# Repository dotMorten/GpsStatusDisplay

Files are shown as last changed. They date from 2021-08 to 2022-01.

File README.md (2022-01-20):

# High Accuracy GPS Device Build


Build your own survey-grade super-accurate GPS Device at a fraction of the cost.
The below list will run you around $300 (mainly for the advanced GPS chip), but will rival high-end GPS receivers that'll often cost you up towards $10000, not to mention you get a built-in interface for configuring the device, instead of relying on external desktop or mobile software.

### Features:
 - Up to 10mm accuracy with RTCM Correction Source
 - 128x128 RGB OLED Display for status and configuration
 - Bluetooth and Serial Port connections
 - 5-way button to control display and configure device
 
 ### Parts List:
 1. High-accuracy GPS Chip: [SparkFun GPS-RTK2 Board - ZED-F9P (Qwiic) High-Precision Breakout](https://amzn.to/2HEfFoN)
 2. GNSS Multi-Band Antenna : [GNSS Multi-Band Magnetic Mount Antenna - 5m (SMA)](https://www.sparkfun.com/products/15192)
 3. Antenna Ground Plate: [GPS Antenna Ground Plate](https://www.sparkfun.com/products/15004)
 4. UFL-to-SMA antenna connector: [Karcy Mini PCI UFL to SMA Female Connector](https://amzn.to/34DS7c4)
 5. Bluetooth chip: [SparkFun Bluetooth Silvermate](https://amzn.to/35LofKn)
 6. Arduino: [SparkFun Thing Plus - SAMD51](https://amzn.to/3kK7pSq)
 7. Display: [Waveshare 1.5inch RGB OLED Display Module](https://amzn.to/3oGIIsc)
 8. Buttons: 4 6x6mm tactile buttons
 9. Qwiic connector: [SparkFun Qwiic Cable Kit Hook Up](https://amzn.to/2TBvj6r)
 10. Various cables/connectors for soldering it all together
 
You really only need 1-4, if you don't need a display. Add 5 if you want bluetooth. However without the Arduino, display and buttons, all configuration has to be done via the u-blox desktop software.
For antenna you can pretty much use any GPS antenna rated for multi-band L1 and L2, but the above combined with the ground plate is likely the cheapest option while supporting full 10mm RTK.

### Resources

- [SparkFun GPS-RTK2 Hookup Guide](https://learn.sparkfun.com/tutorials/gps-rtk2-hookup-guide)
- [NmeaParser](https://github.com/dotMorten/NmeaParser) - My library to process NMEA data from the device, as well as sending it NTRIP Correction Data for full RTK 10mm accuracy
- [SparkFun u-blox Arduino Library](https://github.com/sparkfun/SparkFun_Ublox_Arduino_Library)
- [UcgLib](https://github.com/olikraus/ucglib) - Display library used for rendering to the OLED display

### Display example:
gpsdisplay_4
 
### Connection Diagram



### Accuracy

With an RTCM Correction source such as an NTRIP service, you can get down to around 10mm accuracy. As an example here's the point plot of 1000 measurements in RTK mode with an RTCM base station ~7.7 km away.



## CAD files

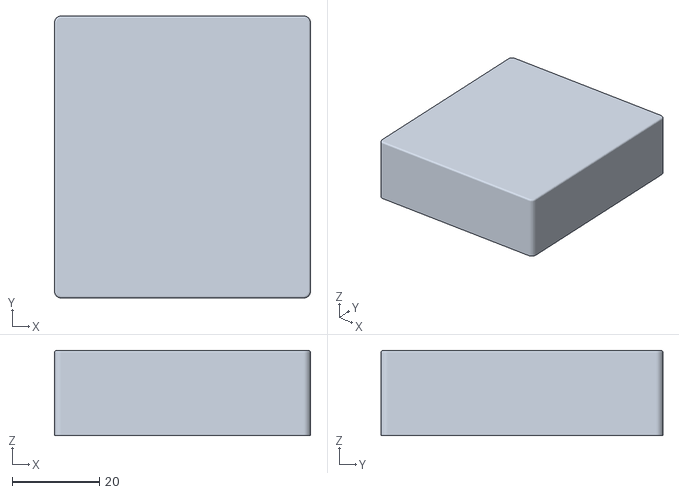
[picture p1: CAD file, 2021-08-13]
3dPrints/Box.stl
58.6 x 64.6 x 19.5

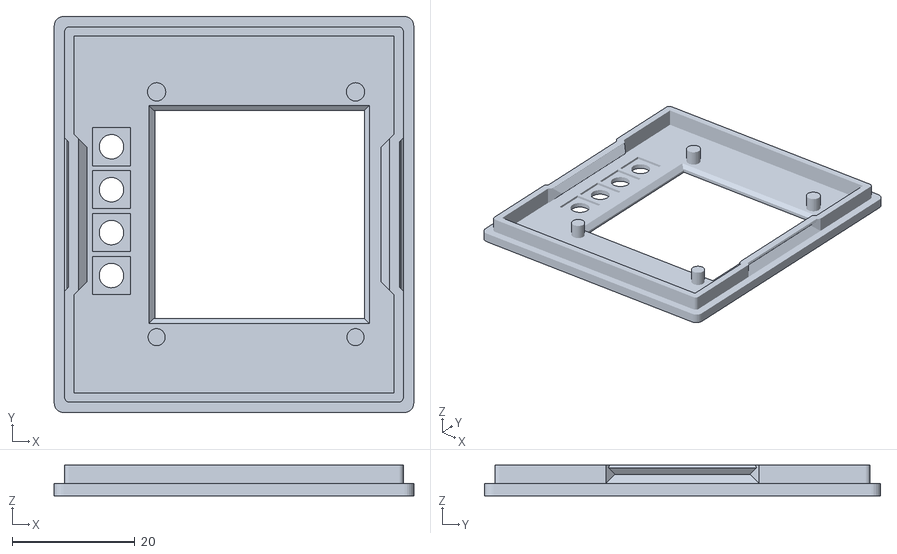
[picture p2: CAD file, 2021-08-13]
3dPrints/Lid.stl
58.6 x 64.6 x 5.00

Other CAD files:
3dPrints/BoxDesign.f3d

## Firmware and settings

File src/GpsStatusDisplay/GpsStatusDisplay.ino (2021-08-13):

/*
  09/16/2020
  Author: Morten Nielsen
  Platforms: SAMD51
  Language: C++
  File: GpsStatusDisplay.ino

  3rd party libs used:
  ucglib : https://github.com/olikraus/ucglib  v1.5.2 http://librarymanager/All#Ucglib
  SparkFun u-blox lib: https://github.com/sparkfun/SparkFun_u-blox_GNSS_Arduino_Library
*/

#include <Wire.h>
#include <Ucglib.h> //http://librarymanager/All#Ucglib

// Initialize the OLED display:
Ucglib_SSD1351_18x128x128_FT_HWSPI ucg(/*cd=*/ 1, /*cs=*/ 0, /*reset=*/ 4);

#include "SparkFun_u-blox_GNSS_Arduino_Library.h"
#include "GnssMonitor.h"
#include "drawhelpers.h"
#include "Menu.h"
#include "buttons.h"
#include "bitmaps.h"
#include "statuspages.h"
#include "settingsMenu.h"

bool ledstate;
bool isDisplayOff;
SFE_UBLOX_GNSS gps;
Menu *currentMenu = nullptr;
bool isInitializing = true;
bool gpsConnectionError = false;

int16_t currentDisplay = 2;

void showDisplay(bool newPage)
{
   if(isDisplayOff)
     return;
   drawStatusBar(newPage);
   if (currentMenu)
     return;
   if(gpsConnectionError)
     return;
   if(currentDisplay == 0)
      drawPage_ErrorInfo(newPage);
   else if(currentDisplay == 1)
      drawPage_NavigationInfo(newPage);
   else if(currentDisplay == 2)
      drawPage_LocationInfo(newPage);
}
void drawStatusBar(bool newPage)
{
  ucg.setFont(ucg_font_helvR08_hr);  
  ucg.setFontMode(UCG_FONT_MODE_SOLID);
  
  if(newPage && currentMenu==nullptr) {
    ucg.setColor(255, 255, 0);
    ucg.drawHLine(0,10,128);
  }
  
  if(gpsConnectionError)
  {
    ucg.setColor(255, 0, 0);
    ucg.setPrintPos(20,64);
    ucg.print("ERROR: GPS CHIP");
    ucg.setPrintPos(20,84);
    ucg.print("NOT DETECTED");
    return;
  }
  
  //Fix quality
  String m;
  int q = quality();
  ucg.setColor(0,255,0);
  if(q == 0)
  {
    ucg.setColor(255,0,0);
    m = "No Fix";
  }
  else if(q == 1)
     m = "GPS   ";
  else if(q == 2)
     m = "DIFF  ";
  else if(q == 3)
     m = "PPS   ";
  else if(q == 4)
     m = "RTK   ";
  else if(q == 5)
  {
    ucg.setColor(255,255,0);
    m = "FLOAT ";
  }
  else {
    ucg.setColor(255,0,0);
     m = "---   ";
  }
  ucg.setPrintPos(0,8);
  ucg.print(m);

  // Horizontal error
  String str = "      ";
  auto err = horizontalError();
  if(!isnan(err)) {
    int decimals = 1;
    if(err < .02)
      decimals = 3;
    else if(err < .2)
      decimals = 2;
    else if(err < 2)
      decimals = 1;
    str = " " + String(err, decimals) + "m  ";
  }
  auto width = ucg.getStrWidth(str.c_str());
  ucg.setColor(255, 255, 0);
  ucg.setPrintPos(64-width/2+1,8); 
  ucg.print(str.c_str());
  if(!isnan(err))
    drawBitmap(64-width/2-3, 1, 5, 7, plusminus, 255, 255, 0);

  // Satellite count
  if(newPage)
    drawBitmap(100, 1, 10, 6, satBitmap, 255, 255, 0);
  ucg.setColor(255, 255, 0);
  ucg.setPrintPos(115,8);
  ucg.print(String(sats()).c_str());
}
const int buttonPin = 10;
unsigned long lastButtonPressTime;
//MenuItem menu;

bool hasNewData = false;
void onPVTDataChanged(UBX_NAV_PVT_data_t pvt)
{
  if(ledstate)
    digitalWrite(LED_BUILTIN, HIGH);
  else
    digitalWrite(LED_BUILTIN, LOW);
  ledstate = !ledstate;

  onPVTDataChanged_(pvt);
  hasNewData = true;
}
void OnHPPOSLLHChanged(UBX_NAV_HPPOSLLH_data_t hppos)
{
  OnHPPOSLLHChanged_(hppos);
  hasNewData = true;
}
void OnDOPChanged(UBX_NAV_DOP_data_t dop)
{
  OnDOPChanged_(dop);
  hasNewData = true;
}
void configureGps()
{
  //Wire.setClock(400000); //Increase I2C clock speed to 400kHz
  gps.setI2COutput(COM_TYPE_UBX); //Sets I2C to communicate with just the UBX protocol
  // Ensure UART2 bluetooth is configured correctly: 115200 baud, 1 stopbit, 8 databits, parity none(0)
  gps.setVal32(UBLOX_CFG_UART2_BAUDRATE, 115200, VAL_LAYER_FLASH + VAL_LAYER_RAM + VAL_LAYER_BBR);
  gps.setVal8(UBLOX_CFG_UART2_STOPBITS, 1, VAL_LAYER_FLASH + VAL_LAYER_RAM + VAL_LAYER_BBR);
  gps.setVal8(UBLOX_CFG_UART2_DATABITS, 8, VAL_LAYER_FLASH + VAL_LAYER_RAM + VAL_LAYER_BBR);
  gps.setVal8(UBLOX_CFG_UART2_PARITY, 0, VAL_LAYER_FLASH + VAL_LAYER_RAM + VAL_LAYER_BBR);

  //gps.enableDebugging(Serial, true); 
  gps.setAutoPVTcallback(onPVTDataChanged);
  gps.setAutoHPPOSLLHcallback(OnHPPOSLLHChanged);
  gps.setAutoDOPcallback(OnDOPChanged);
}

void setup()
{
  Serial.begin(115200);
  // while (!Serial); //Wait for user to open terminal
  Serial.println("App start");
  lastButtonPressTime = millis();
  Wire.begin();   
#if defined(AM_PART_APOLLO3)
  Wire.setPullups(0); // On the Artemis, we can disable the internal I2C pull-ups too to help reduce bus errors
#endif
  //Serial1.setTimeout(10);
  initButtons();
  pinMode(LED_BUILTIN, OUTPUT);
  ucg.begin(UCG_FONT_MODE_SOLID);
  ucg.clearScreen();
  
  ucg.setColor(255, 255, 255);
  ucg.setFontMode(UCG_FONT_MODE_SOLID);

  int count = 0;
  bool gpsStarted = gps.begin(Wire);
  while(!gpsStarted && count < 20)
  {    
    delay(100); // Wait for GPS to start up
    gpsStarted = gps.begin(Wire);
    count++;
  }
  if(!gpsStarted)
      gpsConnectionError = true;
  if(!gpsConnectionError){
    configureGps();
  }
  initSettingsMenu(&gps);
  showDisplay(true);
  menu->setDisplay(&ucg);
  digitalWrite(LED_BUILTIN, HIGH);
}

int buttonState = KEY_NONE;
void loop()
{
  bool requireFullRedraw = false;
  
  if(!gpsConnectionError)
    gps.checkUblox(); // Check for the arrival of new data and process it.
    gps.checkCallbacks(); // Check if any callbacks are waiting to be processed. 
  // Flash LED on each new data
  if(!hasNewData)
  {
    delay(1);
  }
  // Process UI
  
  auto t = millis();
  auto newButtonState = getButtonState();
  if(t - lastButtonPressTime > 30000 && !isDisplayOff)
  {
    // Turn display off after 30 seconds of not pressing any button
    isDisplayOff = true;
    ucg.powerDown();
    currentMenu = nullptr;
  }
  else if(newButtonState != KEY_NONE && isDisplayOff)
  {
    // A key was pressed -> Turn screen back on
    isDisplayOff = false;
    ucg.clearScreen();
    ucg.powerUp();
    requireFullRedraw = true;
  }
  else if(currentMenu == nullptr && newButtonState == KEY_LEFT && buttonState == KEY_LEFT && t - lastButtonPressTime > 1000)
  {  
    //Enter menu on hold
    currentMenu = menu;
    menu->reset();
    menu->initScreen();
  }
  else if(currentMenu) // A menu is currently active
  {
    auto result = processMenu(currentMenu, &gps);
    if(result == MENU_RESULT_EXIT)
    {
      currentMenu = nullptr;
      ucg.clearScreen();
      requireFullRedraw = true;
    }
  }
  else if (newButtonState != buttonState && newButtonState != KEY_NONE)
  {
    // flip status pages
    if(newButtonState == KEY_RIGHT || newButtonState == KEY_DOWN)
    {
      currentDisplay++;
      if(currentDisplay > 2)
        currentDisplay = 0;
    }
    else if(newButtonState == KEY_UP || newButtonState == KEY_LEFT)
    {
      currentDisplay--;
      if(currentDisplay < 0)
        currentDisplay = 2;
    }
    ucg.clearScreen();
    requireFullRedraw = true;
  }
  if(hasNewData || requireFullRedraw)
    showDisplay(requireFullRedraw);
  if (newButtonState != buttonState)
      lastButtonPressTime = t; //reset button press inactivity timer
  buttonState = newButtonState;
  hasNewData = false;
}

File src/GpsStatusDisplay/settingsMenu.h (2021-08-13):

#ifndef __settingsMenu_h__
#define __settingsMenu_h__

#include "ubloxextensions.h"

const int CONNECTIONSMENUID=10;
const int NMEAMENUID=20;
const int NMEAMSGMENUID = NMEAMENUID + 100; //NOTE This goes to 120..132
const int GNSSMENUID=50;
const int ABOUTMENUID=80;
const int USBSETTINGSMENUID = CONNECTIONSMENUID+100;
const int BLUETOOTHSETTINGSMENUID = CONNECTIONSMENUID+200;
  MenuItem *gnssMenuItems[] =
  {
    new MenuItem(GNSSMENUID + 6, "Rate", "---"),
    new MenuItem(GNSSMENUID + 5, "High Precision", "On"),
    new MenuItem(GNSSMENUID + 1, "GPS", "Enabled"),
    new MenuItem(GNSSMENUID + 2, "GLONASS", "Enabled"),
    new MenuItem(GNSSMENUID + 3, "Galileo", "Enabled"),
    new MenuItem(GNSSMENUID + 4, "Beidou", "Enabled"),
  };
  MenuItem *aboutMenuItems[] =
  {
    new MenuItem(ABOUTMENUID + 1, "Version", "1.0"),
    new MenuItem(ABOUTMENUID + 2, "Device Info"),
    new MenuItem(ABOUTMENUID + 3, "Reset"),
    new MenuItem(ABOUTMENUID + 4, "Privacy Mode", "Off"),
  };
  MenuItem *connectionsMenuItems[] =
  {
    new MenuItem(CONNECTIONSMENUID + 1, "USB", "---"),
    new MenuItem(CONNECTIONSMENUID + 2, "Bluetooth", "---"),
  };
  MenuItem *enabledNmeaMessagesItems[] = {    
    new MenuItem(NMEAMSGMENUID, "GGA", "--", UBLOX_CFG_MSGOUT_NMEA_ID_GGA_USB),
    new MenuItem(NMEAMSGMENUID, "GLL", "--", UBLOX_CFG_MSGOUT_NMEA_ID_GLL_USB),
    new MenuItem(NMEAMSGMENUID, "GSA", "--", UBLOX_CFG_MSGOUT_NMEA_ID_GSA_USB),
    new MenuItem(NMEAMSGMENUID, "GSV", "--", UBLOX_CFG_MSGOUT_NMEA_ID_GSV_USB),
    new MenuItem(NMEAMSGMENUID, "RMC", "--", UBLOX_CFG_MSGOUT_NMEA_ID_RMC_USB),
    new MenuItem(NMEAMSGMENUID, "VTG", "--", UBLOX_CFG_MSGOUT_NMEA_ID_VTG_USB),
    new MenuItem(NMEAMSGMENUID, "GRS", "--", UBLOX_CFG_MSGOUT_NMEA_ID_GRS_USB),
    new MenuItem(NMEAMSGMENUID, "GST", "--", UBLOX_CFG_MSGOUT_NMEA_ID_GST_USB),
    new MenuItem(NMEAMSGMENUID, "ZDA", "--", UBLOX_CFG_MSGOUT_NMEA_ID_ZDA_USB),
    new MenuItem(NMEAMSGMENUID, "GBS", "--", UBLOX_CFG_MSGOUT_NMEA_ID_GBS_USB),
    new MenuItem(NMEAMSGMENUID, "DTM", "--", UBLOX_CFG_MSGOUT_NMEA_ID_DTM_USB),
    new MenuItem(NMEAMSGMENUID, "GNS", "--", UBLOX_CFG_MSGOUT_NMEA_ID_GNS_USB),
    new MenuItem(NMEAMSGMENUID, "VLW", "--", UBLOX_CFG_MSGOUT_NMEA_ID_VLW_USB),
  };
    MenuItem *nmeaSettingsMenuItems[] =
  {
    new MenuItem(NMEAMENUID + 1, "Version", "---"),
    new MenuItem(NMEAMENUID + 2, "Messages", enabledNmeaMessagesItems, 13),
    new MenuItem(NMEAMENUID + 3, "High Precision", "--"), // Enable high precision mode: CFG_NMEA_HIGHPREC  on/off
    new MenuItem(NMEAMENUID + 4, "Compat Mode", "--"), // NMEA Compat mode: On/Off  CFG-NMEA-COMPAT (0x10930003)
    new MenuItem(NMEAMENUID + 5, "Limit 82 chars", "--"), // Enable strict limit to 82 characters maximum NMEA message length: On/Off  - CFG-NMEA-LIMIT82 (0x10930005)
  };

  MenuItem *mainMenuItems[] =
  {
    new MenuItem(1, "Outputs", connectionsMenuItems, 2),
    new MenuItem(2, "NMEA", nmeaSettingsMenuItems, 5),
    new MenuItem(3, "RTCM", ">"),
    new MenuItem(4, "SBAS", "---"),
    new MenuItem(5, "GNSS", gnssMenuItems, 6),
    new MenuItem(6, "Info/About", aboutMenuItems, 4)
  };
Menu *menu = new Menu(new MenuItem(0, "Settings", mainMenuItems, 6));
MenuItem *gpsInfoMenu[] =
    {
      new MenuItem(0, "Hardware Version"),
      new MenuItem(0, "---"),
      new MenuItem(0, "Software Version"),
      new MenuItem(0, "---"),
      new MenuItem(0, ""),
      new MenuItem(0, ""),
      new MenuItem(0, ""),
      new MenuItem(0, ""),
      new MenuItem(0, ""),
      new MenuItem(0, ""),
      new MenuItem(0, ""),
      new MenuItem(0, ""),
      new MenuItem(0, ""),
    };
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

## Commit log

2020-09-27 minor tweaks and fixes
    [GpsStatusDisplay.ino]
2020-10-12 Switched to UCG lib
2020-10-30 bug fixes and clean up
    [GpsStatusDisplay.ino, settingsMenu.h]
2021-01-04 Address some i2c bus errors
    [GpsStatusDisplay.ino]
2021-08-13 Fix usb settings menu
    [settingsMenu.h]
2021-08-13 Change controls from 5-button to 4-button inputs
2021-08-13 3D Print models
    [Box.stl, BoxDesign.f3d, Lid.stl]
2021-08-13 Fix setter (thanks @eito)
    [settingsMenu.h]
